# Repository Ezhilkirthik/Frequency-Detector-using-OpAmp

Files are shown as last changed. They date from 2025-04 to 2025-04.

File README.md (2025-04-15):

# Frequency Detection Circuit Using Op-Amps

## Overview

This project involves the design, simulation, and implementation of a frequency detection circuit using operational amplifiers. The circuit converts an unknown sinusoidal input signal into a DC voltage proportional to its frequency. The project includes schematic and PCB design files, simulation results, and a detailed technical report.

---

## 📌 Objective

To create a circuit capable of detecting the frequency of a sinusoidal signal and converting it into a measurable DC voltage, enabling frequency analysis without an oscilloscope or frequency counter.

---

## 🧠 Working Principle

1. **Signal Conditioning**: The sinusoidal input is first conditioned using an op-amp-based zero-crossing detector to generate a square wave.
2. **Monostable Multivibrator**: Converts each cycle into a pulse of fixed duration.
3. **Integrator or Low-Pass Filter**: Averages the pulse train into a DC voltage that varies linearly with frequency.
4. **Output Stage**: The final DC output can be read using a multimeter.

---

## 🔧 Tools and Technologies Used

- **LTspice**: For simulating and validating the circuit behavior.
- **EAGLE**: For schematic design and PCB layout.
- **Op-Amps**: Used for signal processing stages (e.g., LM324 or equivalent).
- **Multimeter**: To measure the output DC voltage corresponding to frequency.

---

## 🗂️ Project Files

| File | Description |
|---|---|
| `PCB design.brd` | EAGLE board layout file |
| `PCB design.sch` | EAGLE schematic file |
| `PCB design.png` | Schematic/PCB image preview |
| `README.md` | Project documentation |
| `Report on Frequency Detector.pdf` | Detailed explanation of theory, design, calculations, and results |
| `design blocks.dbl` | Block diagram or design structure file (assumed for visual layout or planning) |
| `*.asc` / LTspice files | Simulation circuits and results |

---

## ✅ Features

- Converts sinusoidal signals (variable frequency) to a DC voltage output.
- Linear relationship between frequency and voltage.
- Suitable for real-time monitoring with minimal hardware.
- Compact and low-cost solution.

---

## 📈 Simulation and Testing

- Simulated using LTspice to validate performance and linearity.
- Output voltage was tested across a range of frequencies to confirm consistency.
- PCB designed and reviewed for real-world implementation.

---

## 🧪 Applications

- Educational demonstration of frequency detection.
- Basic instrumentation projects.
- Embedded systems requiring analog frequency monitoring.
- Low-cost signal analysis setups.

---

## 📎 How to Use

1. Connect the sinusoidal input signal to the input terminal of the circuit.
2. Power the op-amp circuit with the recommended dual or single power supply.
3. Read the output voltage using a multimeter.
4. Use the linear transfer function (from report) to interpret the frequency.

---

## 📃 Documentation

Please refer to `Report on Frequency Detector.pdf` for:

- Complete theoretical background
- Circuit analysis and calculations
- Design decisions
- PCB snapshots
- Testing and result interpretation

---

## 📌 Notes

- Ensure proper power supply filtering for accurate readings.
- Input signal should be within expected amplitude range for reliable zero-crossing detection.
- Calibration may be required depending on the op-amp and resistor tolerances used.

---

## 🛠️ Future Improvements

- Add microcontroller interface to digitally display the frequency.
- Expand range using frequency dividers or advanced signal conditioning.
- Implement auto-scaling for broader frequency bands.

---

## 👨‍💻 Author

*Ezhilkirthik M*  
*AMRITA SCHOOL OF ENGINEERING, AMRITA VISHWA VIDYAPEETHAM *  
*Date: 01 April 2025*

---

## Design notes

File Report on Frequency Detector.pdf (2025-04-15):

### 23ECE286 CIRCUITS AND COMMUNICATION LAB

### Design and implementation of a circuit using op-amps to find the frequency of a sinusoidal signal

TERM PROJECT REPORT

Submitted by

CB.EN.U4ECE23010 | BATTULA UDAY VENUGOPAL
CB.EN.U4ECE23016 | EZHILKIRTHIK M
CB.EN.U4ECE23018 | SRUJANA KARRI

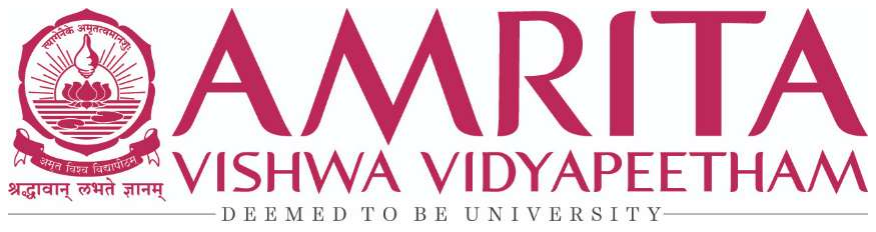
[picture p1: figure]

AMRITA SCHOOL OF ENGINEERING AMRITA VISHWA VIDYAPEETHAM

COIMBATORE 641112
April 2025
Date of Submission
(01/04/2025)

Students signature

Faculty | Lab Staff

2

### Table of Contents

Topic | Page No.
Introduction | 4
Objectives | 4
Methodology | 5
Circuit Design and Components | 6
Implementation | 7
Results | 8
Discussion | 14
Challenges and Solutions | 14
Conclusion | 15
References | 15

3

4

### Introduction

The ability to determine the frequency of a given input signal is essential in various applications such as communication systems, instrumentation, and signal processing. This project aims to design and implement a circuit that can detect the frequency of a sinusoidal signal without prior knowledge of its frequency. The key approach is to convert the frequency into a measurable DC equivalent, which varies with changes in frequency.

Problem Statement and Explanation

The primary challenge in this project is to develop a method to detect the frequency of a sinusoidal signal and represent it as a DC voltage output. This allows for an easy and precise measurement using a multimeter. The circuit must maintain linearity between the frequency and the output voltage, ensuring an accurate and predictable response.

Objectives

- To design a circuit that converts frequency into a readable DC voltage output.
- To ensure the output voltage varies proportionally with the input signal frequency.
- To maintain linearity in the frequency-to-voltage conversion.
- Validating the circuit performance through simulation, analysis and hardware implementation.

Breakup of Goals

### 1. Implement a differentiator circuit to extract frequency-dependent amplitude

variation.
2. Use a precision rectifier to obtain a measurable DC output.
3. Evaluate circuit performance through LTSpice simulations.
4. Validate linearity of the circuit’s frequency response.
5. Optimize the design for improved accuracy and reliability.

5

### Methodology

To achieve the project objectives, the following approach was taken:

### 1. Circuit Design: A differentiator circuit followed by a precision rectifier was

designed to achieve frequency-to-voltage conversion.

### 2. Simulation: The circuit was simulated using LTSpice to validate its

performance.

### 3. Analysis: The output voltage was measured at different input frequencies to

establish a frequency-to-voltage relation.
4. Optimization: The circuit was fine-tuned to maintain linearity and stability.

Why a Differentiator Circuit?

A differentiator circuit was used because differentiation of a sinusoidal input results in an output where the frequency component appears as a multiplying factor in the amplitude. Mathematically, if the input is given by Ac sin (⍵t), the differentiated

### output becomes ⍵Ac cos(⍵t) . This means that the amplitude of the output is directly proportional to the frequency, making it easier to extract a frequency-dependent signal. The differentiated signal is then processed further to obtain a

readable DC output.

Why a Precision Rectifier?

A precision rectifier was used to convert the AC signal obtained from the differentiator into a DC voltage. Standard diode rectifiers introduce voltage drops that affect accuracy, especially for low-amplitude signals. Using an op-amp-based precision rectifier eliminates these losses and ensures accurate rectification. This allows for a reliable DC representation of the frequency-dependent signal, which can be measured with a multimeter.

6

### Circuit Design and Components

The circuit consists of:

### 1. Differentiator Circuit

- Converts the sinusoidal signal into a frequency-dependent amplitude-modified waveform.
- Based on the principle: d/dt [A sin(ωt)] = ωA cos(ωt), where the frequency component ω appears in the amplitude.

### 2. Precision Rectifier Circuit

- Converts the differentiated AC signal into a DC output.
- Provides accurate rectification even for low-amplitude signals.

### 3. Key Components and Their Roles:

Component | Specification | Quantity
Op-Amp | LM741 | 2
Resistors | 1kΩ, 10kΩ | 1, 3
Capacitors | 10nF | 1
Diodes | 1N4148 | 2
Power Supply | +15V, -15V | 1
Digital Storage Oscillator | | 1
Probes | | 3

7

Bread board | 1
Connecting wires | as required
- Op-Amps (LM741): Used for differentiation and precision rectification.
- Resistors (1kΩ, 10kΩ): Define circuit response characteristics.
- Capacitors (10nF): Used in the differentiator for frequency-dependent behavior.
- Diodes (1N4148): Provide rectification in the precision rectifier stage.
- Power Supply (+15V, -15V): Powers the op-amps.

### Implementation

The circuit was built and tested in LTSpice simulation software. Initially, a peak detector was considered for generating the DC output, but it was found to distort the linearity in frequency analysis. The peak detector was replaced with a precision rectifier to maintain linearity.

- The simulation results showed a clear relationship between the output voltage and input frequency.
- AC analysis confirmed the linearity of the circuit.
- Frequency-to-voltage mapping was established for practical measurement.

### Results:

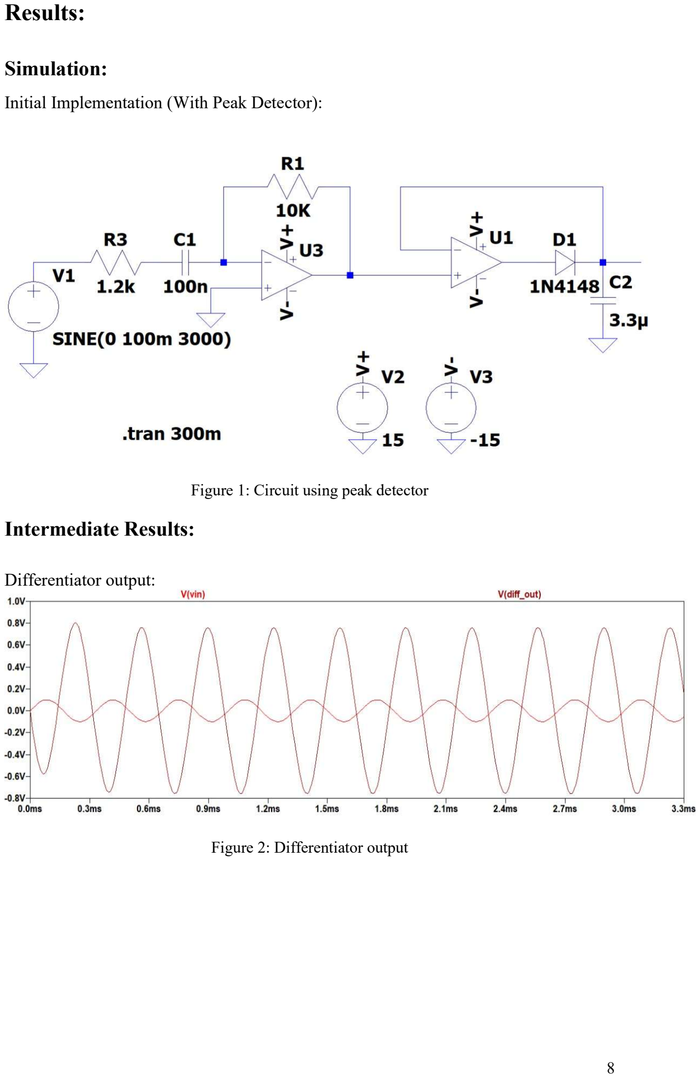
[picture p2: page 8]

8

Simulation:

Initial Implementation (With Peak Detector):

Figure 1: Circuit using peak detector
Intermediate Results:

Differentiator output:

Figure 2: Differentiator output

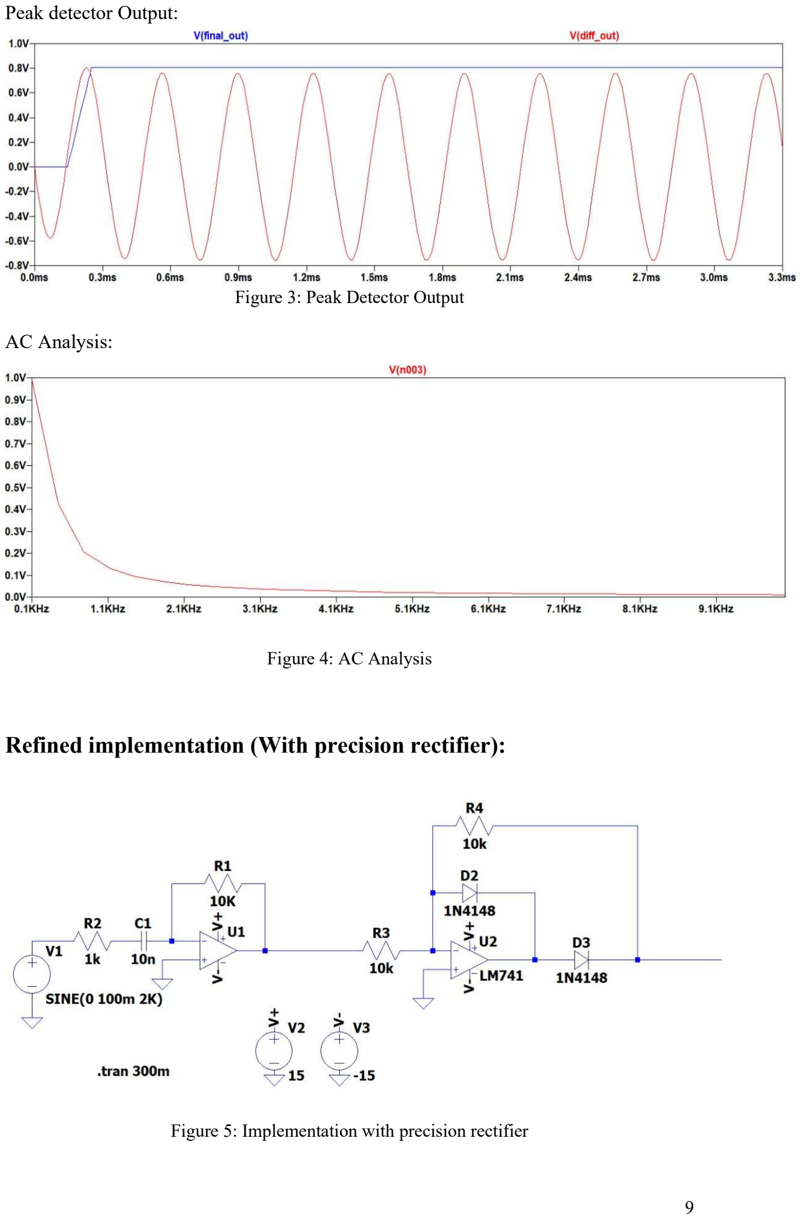
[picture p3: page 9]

9

Peak detector Output:

Figure 3: Peak Detector Output

AC Analysis:

Figure 4: AC Analysis

Refined implementation (With precision rectifier):

Figure 5: Implementation with precision rectifier

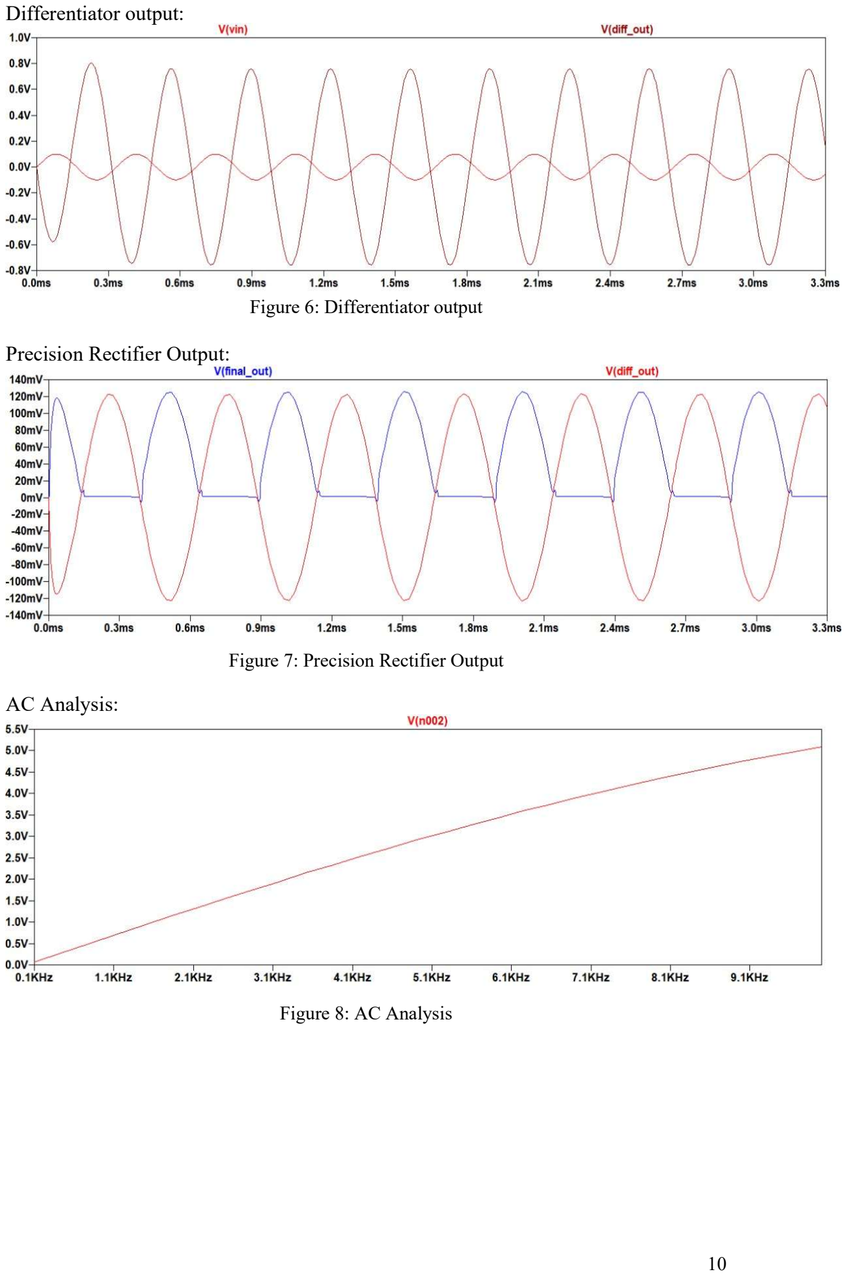
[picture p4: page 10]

10

Differentiator output:

Figure 6: Differentiator output

Precision Rectifier Output:

Figure 7: Precision Rectifier Output

AC Analysis:

Figure 8: AC Analysis

## Hardware Implementaon

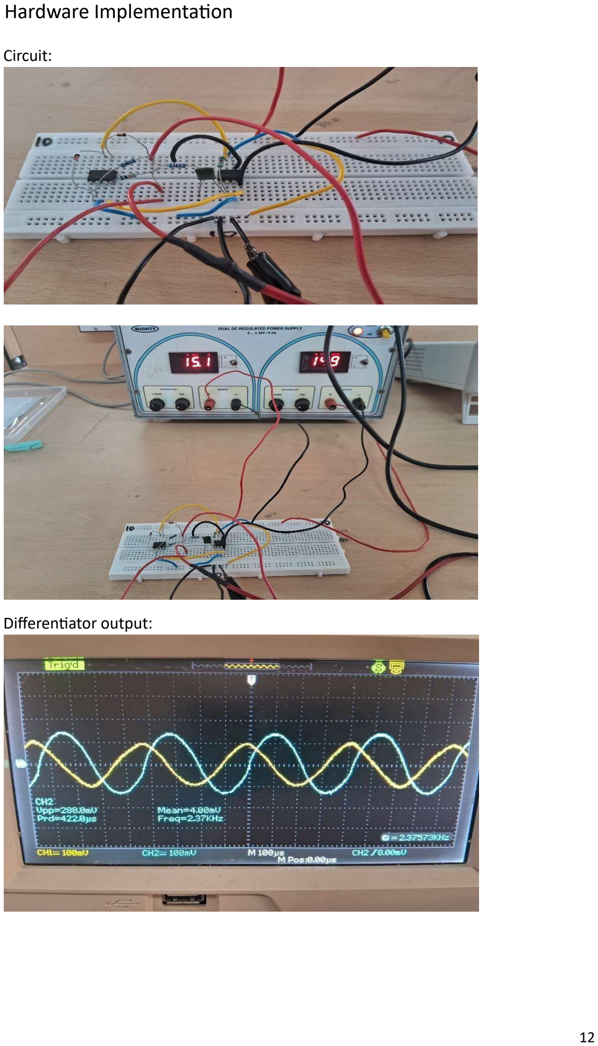
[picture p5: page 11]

Circuit:

Differenator output:

12

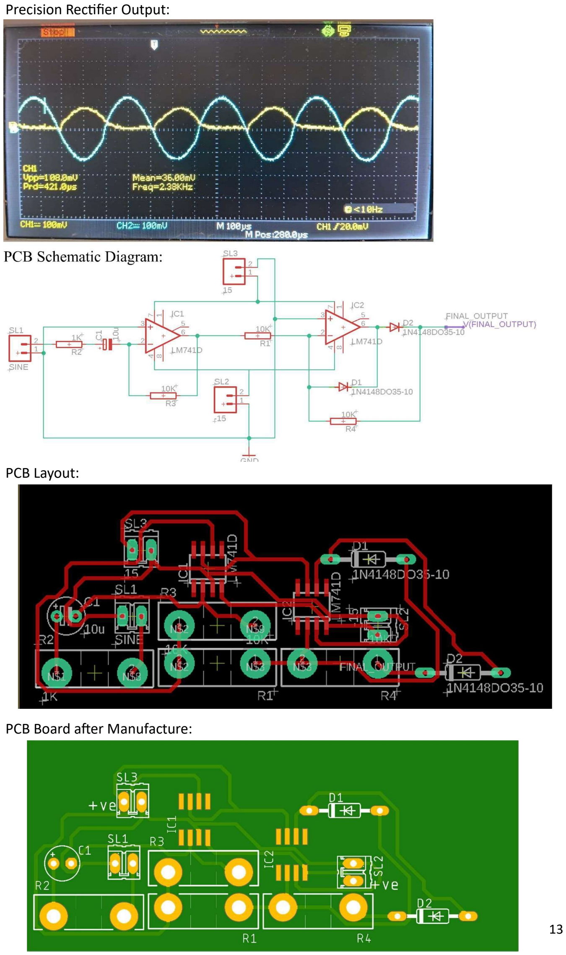
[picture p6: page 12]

Precision Recfier Output:

PCB Layout:

PCB Board aer Manufacture:

13

13

Results (Tabulated for frequencies and their corresponding DC outputs):

Frequency(Hz) Voltage(mV)

300
500
700
900
1000
1200
1400
1600
1800
2000
2500
3000
3500
4000
4500
5000
5500
6000
6500
7000
7500
8000
8500
9000

6.6
11.1
15.6
20.2
22.5
27
31.5
35.9
40.3
44.7
55.7
66.3
76.9
87.1
97.1
106.8
116.3
125.4
134.2
142.6
150.6
158.4
165.7
172.9

Table 1. Output from Hardware implementation

Graph:

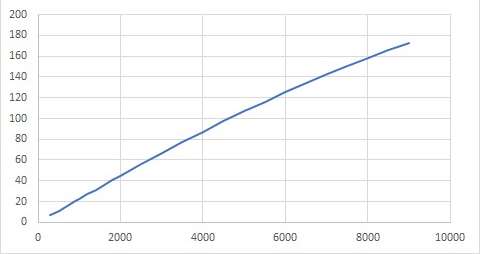
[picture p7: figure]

Figure 13: AC Analysis

14

Relation:
Linear Equation:

Voltage (mV) = 0.01952×Frequency (Hz)+4.8803

Nonlinear Equation:

Frequency (Hz) = 28.99 * (Voltage (in mV))¹.1096

Quadratic Relation:

Frequency (Hz) = 0.0743(Voltage (in mV))² + 38.0884(Voltage (in mV)) +106.78

The quadratic equation and nonlinear equation are a better representation because the circuit contains a diode, which introduces a strong non-linearity. Additionally, the RC filter's frequency-dependent behavior also contributes to the non-linear relationship. The combination of these effects makes the quadratic equation a more accurate model of the circuit's output. The exact nature of the nonlinearity depends on the specific operating conditions and component values. However, in this case, the quadratic fit is clearly superior to the linear fit.

### Discussion

- The circuit effectively detected frequency variations by converting them into a proportional DC voltage.
- The differentiator approach provided a frequency-dependent amplitude variation, which was successfully rectified.
- Eliminating the peak detector improved the curve fitting, ensuring accurate frequency estimation.

### Challenges and Solutions

### 1. Initial Peak Detector Issue

- Problem: It introduced distortion in the frequency response.
- Solution: Replaced with a precision rectifier for accurate rectification.

### 2. Maintaining Linearity

- Problem: Non-uniform frequency response in the initial tests.
- Solution: Optimized component values and simulation parameters.

15

### Conclusion

The designed circuit successfully converted the input sinusoidal frequency into a measurable DC voltage output with good curve fitting. Future work can include implementing a peak detector and getting a DC output without intermediate distortions.

### References:

1. A. S. Sedra and K. C. Smith, Microelectronic Circuits, 7th ed. New York, NY,
USA: | Oxford | University | Press, | 2014, | pp. | 1012-1015.
(For differentiator and precision rectifier circuit principles)
2. B. Razavi, Design of Analog CMOS Integrated Circuits, 2nd ed. New York,
NY, | USA: | McGraw-Hill, | 2016, | pp. | 254-257.

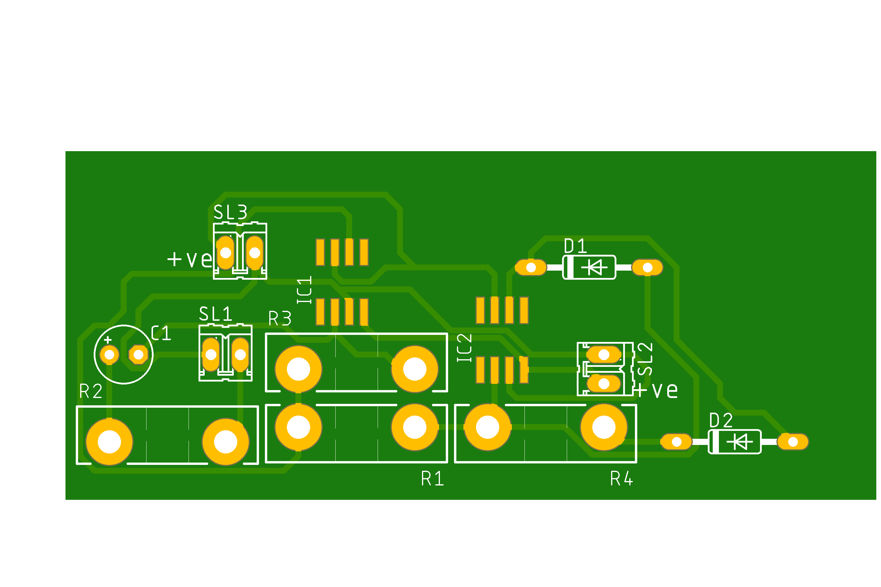
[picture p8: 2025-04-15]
PCB design.png

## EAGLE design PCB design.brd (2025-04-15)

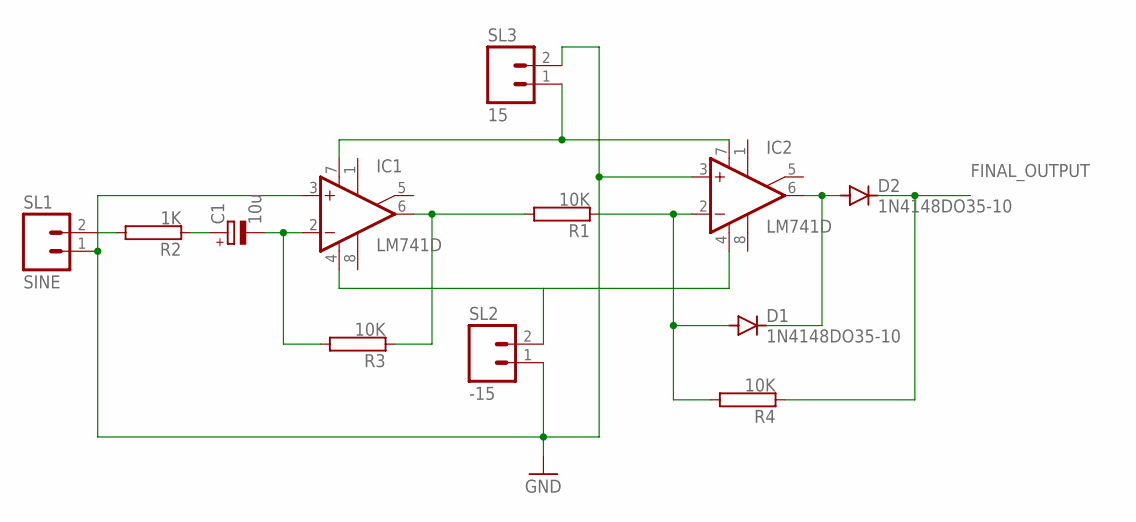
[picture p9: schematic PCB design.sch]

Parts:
C1: 10u; E2,5-5
D1, D2: 1N4148DO35-10; DO35-10
IC1, IC2: LM741D; SO08
R1, R3, R4: 10K; TO-247-2V
R2: 1K; TO-247-2V
SL1: SINE; 02P
SL2: -15; 02P
SL3: 15; 02P

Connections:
FINAL_OUTPUT: D2.C, R4.1
GND: IC1.3 (+IN), IC2.3 (+IN), SL1.1, SL2.1, SL3.2
unnamed: C1.+, R2.1
unnamed: IC1.6 (OUT), R1.2, R3.1
unnamed: D1.A, IC2.2 (-IN), R1.1, R4.2
unnamed: D1.C, D2.A, IC2.6 (OUT)
unnamed: IC1.7 (V+), IC2.7 (V+), SL3.1
unnamed: IC1.4 (V-), IC2.4 (V-), SL2.2
unnamed: R2.2, SL1.2
unnamed: C1.-, IC1.2 (-IN), R3.2

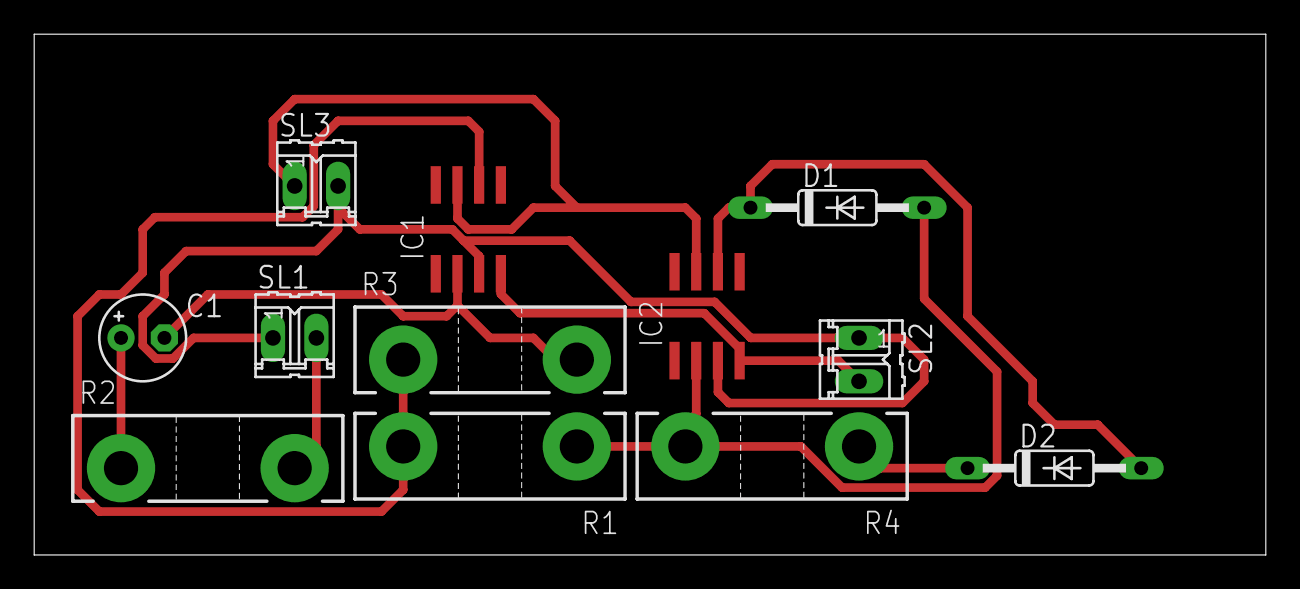
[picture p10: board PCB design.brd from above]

Board: 2 copper layers, 72.1 x 30.5 mm, 12 parts (0 on the bottom side), 10 nets.
